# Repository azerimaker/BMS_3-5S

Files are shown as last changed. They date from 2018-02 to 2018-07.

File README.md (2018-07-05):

# BMS 3-5S
3-5S Battery Management System based on TI bq76920 IC and MSP430 uC. The design is largely influenced by the TI's [TIDA-00449](http://www.ti.com/tool/TIDA-00449) reference and LibreSolar's excellent [BMS-5s](https://github.com/LibreSolar/BMS-5s) designs.

## Specs:
- 3-5 Li-ion/Po Cells
- MSP430 Microcontroller for gas gauging, balancing and serial communication
- Load current: 50A (cont.), 100A (peak) (estimated!)
- You can find the PCB on Seeedstudio's [Fusion Gallery](https://www.seeedstudio.com/BMS-3-5S-g-1092928)

## Programming
- I'm using MSP430 Launchpad both to program the BMS in external target mode and to provide serial communication to PC. 

## Demo
- After modifying the TIDA-00449 firmware, which was designed for bq76930 (10S version) balancing and status report worked fine [(see here)](https://twitter.com/OrkhanAmirAslan/status/1014643359699406849)

## To Do in next Rev. 
- Add simple Python script to decode serial messages and print cell status
- Fix issues with battery voltage switching and Pre-Discharge mosfets. 
- Remove soldermask for high current tracks. 
- More pads for balancing resistors for higher power dissipation. 

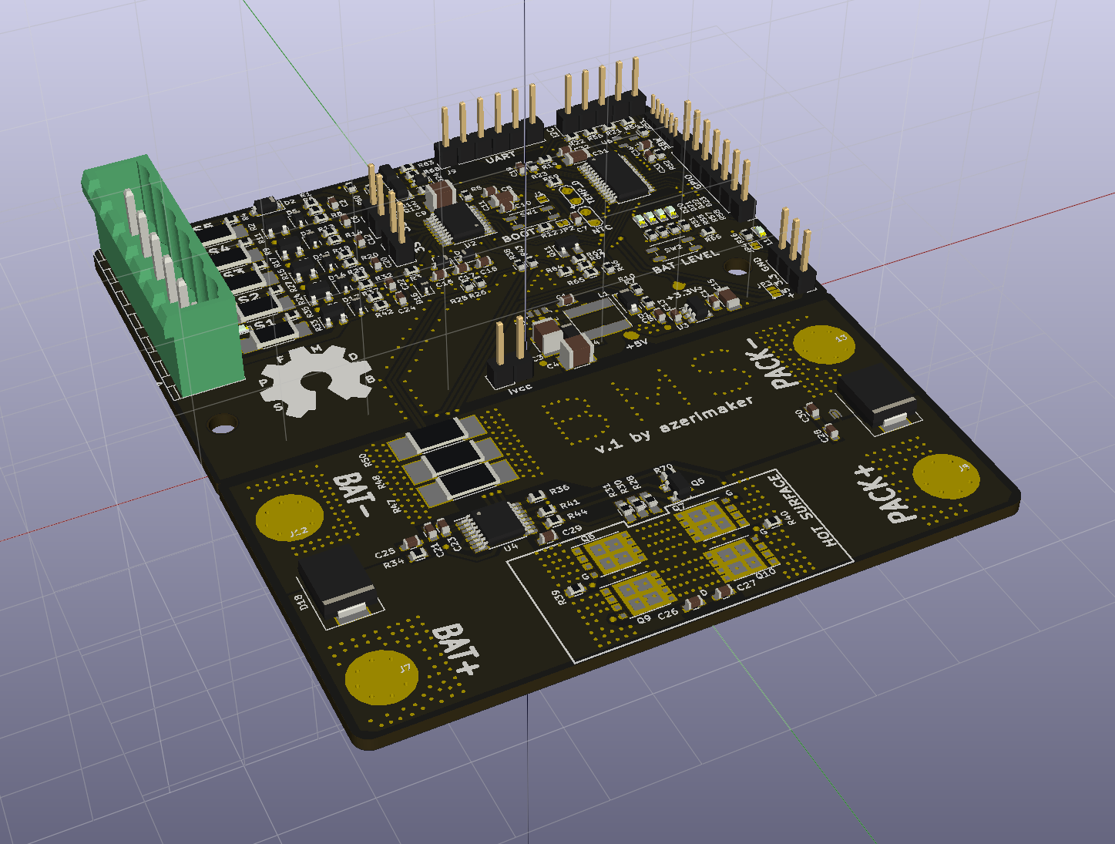
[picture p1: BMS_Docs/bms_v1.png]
BMS_v1 PCB Render


BMS_v1 PCB

<div align="center">
<br /> This work is licensed under a <a rel="license" href="http://creativecommons.org/licenses/by-sa/4.0/">Creative Commons Attribution-ShareAlike 4.0 International License</a>.

</div>

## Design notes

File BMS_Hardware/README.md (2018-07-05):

## BMS 3-5S Hardware Files

KiCAD version 4.0.7 was used.

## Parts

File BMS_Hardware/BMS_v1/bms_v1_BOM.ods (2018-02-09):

Reference | Quantity | Value | PART DESCRIPTION | Part Number | PCB Footprint | URL/Source
C10 C13 C8 | 3 | 1uF | min 10V |  | 0603 | --------------------
C11 C15 C31 | 3 | 4.7uF | CAP CER 4.7UF 50V X7R, min 10V | CL31B475KBHNNNE | 1206 | https://www.digikey.de/scripts/DkSearch/dksus.dll?Detail&itemSeq=247305398&uq=636514169459805309
C1 C12 C16 C17 C18 C2 C20 C22 C24 C32 C34 C6 | 12 | 100nF | - |  | 0603 | --------------------
C26 C27 C28 C30 | 4 | 100nF | CAP, CERM, 0.1uF, 100V, +/-10%, X7R, 0603 | GRM188R72A104KA35D | 0603 | https://www.digikey.de/scripts/DkSearch/dksus.dll?Detail&itemSeq=249808389&uq=636522696778252805
C14 C19 | 2 | 470pF | - |  | 0603 | --------------------
C21 | 1 | 220nF | - |  | 0603 | --------------------
C23 | 1 | 47nF | - |  | 0603 | --------------------
C25 C29 | 2 | 10nF | - |  | 0603 | --------------------
C33 | 1 | 2.2nF | - |  | 0603 | --------------------
C7 | 1 | 4.7nF | - |  | 0603 | --------------------
C3 C4 C5 C9 | 4 | 10uF | CAP CER 10UF 50V X7R | 1276-3387-1-ND | 1210 | https://www.digikey.de/scripts/DkSearch/dksus.dll?Detail&itemSeq=249808060&uq=636522694114372805
D11 | 1 | GREEN | Power Status LED |  | 0603 | --------------------
D6 D3 D8 D13 D15 | 1 | Cell 1-5 | Cell Status LEDs |  | 0603 | --------------------
D10 D16 D24 D9 | 4 | 3.3V | Zener Diode 3.3V 300mW | MM3Z3V3ST1G | SOD-323 | https://www.digikey.de/scripts/DkSearch/dksus.dll?Detail&itemSeq=247304155&uq=636494198338316196
D12 D14 D17 D5 D7 | 5 | 5.6V | Diode, Zener, 5.6V, 200mW | MMSZ5232BS-7-F | SOD-323 | https://www.digikey.de/scripts/DkSearch/dksus.dll?Detail&itemSeq=247269284&uq=636493840967967147
D18 D19 | 2 | SMCJ26A | TVS DIODE 26VWM 42.1V | SMCJ26A-E3/57T | DO-214AB | https://www.digikey.de/product-detail/en/vishay-semiconductor-diodes-division/SMCJ26A-E3-57T/SMCJ26A-E3-57TGICT-ND/2413420
D1 D2 | 2 | 1N4148W | DIODE GEN PURP 100V 300MA | 1N4148W-7-F | SOD-123 | https://www.digikey.de/scripts/DkSearch/dksus.dll?Detail&itemSeq=247300965&uq=636494163483703951
D20 D21 D22 D23 | 4 | Blue | Cell Voltage LEDs |  | 0603 | --------------------
D4 | 4 | DB2W40300L | DIODE SCHOTTKY 40V 3A MINI2 | DB2W40300L | SOD-123F | https://www.digikey.de/product-detail/en/panasonic-electronic-components/DB2W40300L/DB2W40300LCT-ND/3884376
E1 | 1 | SPARK_GAP |  |  | PCB footprint | --------------------
J1 | 1 | BOOT ON/OFF |  |  | Pin Header
J12 | 1 | BATT- |  |  | PCB footprint | --------------------
J13 | 1 | PACK- |  |  | PCB footprint | --------------------
J14 | 1 | I2C_CONN |  |  | Pin Header | --------------------
J15 | 1 | GPIO
J2 | 1 | Vcc_current |  |  | Pin Header | --------------------
J3 | 1 | Thermistor |  |  | Pin Header
J4 | 1 | 3-4S |  |  | Pin Header | --------------------
J5 | 1 | 3S |  |  | Pin Header | --------------------
J6 | 1 | VCC
J7 | 1 | BATT+ |  |  | PCB footprint | --------------------
J8 | 1 | PACK+ |  |  | PCB footprint | --------------------
J9 | 1 | UART |  |  | Pin Header | --------------------
J10 | 1 | SBW |  |  | Pin Header | --------------------
J11 | 1 | Balance Terminal |  |  | Pin Header | --------------------
JP1 JP2 JP4 | 1 | NC |  |  | PCB footprint | --------------------
JP3 | 1 | VCC_SELECT |  |  | PCB footprint | --------------------
L1 | 1 | 22uH | FIXED IND 22UH 1.4A 135 MOHM SMD | NRS6028T220MMGJV | 6.00mm x 6.00mm | https://www.digikey.de/scripts/DkSearch/dksus.dll?Detail&itemSeq=247306594&uq=636494220819346923
Q11 | 1 | RQ5A030AP | MOSFET P-CH 12V 3A TSMT3 | RQ5A030APTL | SC-96 | https://www.digikey.de/product-detail/en/texas-instruments/CSD23381F4/296-40002-1-ND/5177879
Q5 | 1 | ZXMP10A13F | MOSFET P-CH 100V 0.6A | ZXMP10A13FTA | SOT-23-3 | https://www.digikey.de/scripts/DkSearch/dksus.dll?Detail&itemSeq=247257927&uq=636494181879678553
Q10 Q6 Q7 Q9 | 4 | CSD18511Q5AT | N-Channel 40V 159A | CSD18511Q5AT | 8-VSONP | https://www.digikey.de/scripts/DkSearch/dksus.dll?Detail&itemSeq=247302673&uq=636494181879758569
Q1 Q2 Q3 Q4 Q8 | 3 | DMN2004K | MOSFET N-CH 20V 0.63A | DMN2004K-7 | SOT-23-3 | https://www.digikey.de/scripts/DkSearch/dksus.dll?Detail&itemSeq=247269061&uq=636493853394696489
Q12 | 1 | TP0610K-T1-GE3 | HV PFET |  | SOT-23-3 | https://www.digikey.de/scripts/DkSearch/dksus.dll?Detail&itemSeq=248928896&uq=636514210194332359
Q13 | 1 | BSS138 | Gen purpose n-fet |  | SOT-23-3
R10 R12 R13 R18 R29 R37 R52 R59 R6 R67 R68 | 11 | 10K |  |  | 0603 | --------------------
R21 R22 R3 | 3 | 4.7K |  |  | 0603 | --------------------
R23 | 1 | 500K |  |  | 0603 | --------------------
R28 R30 R31 | 3 | 330R |  |  | 0603 | --------------------
R15 R2 R24 R33 R9 | 5 | 33R | RES SMD 33 OHM 1% 1W 2010 | RMCP2010FT33R0 | 2010 | https://www.digikey.de/product-detail/en/stackpole-electronics-inc/RMCP2010FT33R0/RMCP2010FT33R0CT-ND/2505002
R36 R41 | 2 | 4R7 |  |  | 0603 | --------------------
R39 R40 | 2 | 1M |  |  | 0603 | --------------------
R45 R53 | 2 | 0 |  |  | 0603 | --------------------
R49 | 1 | Net-Tie |  |  | 0603 | --------------------
R47 R48 R50 | 3 | 2m | RES 0.002 OHM 1% 3W - 3x 0.006 Ohm | P17094CT-ND | 2512 | https://www.digikey.de/scripts/DkSearch/dksus.dll?Detail&itemSeq=247307811&uq=636494232585020202
R1 R11 R14 R16 R17 R19 R20 R27 R32 R35 R38 R4 R42 R43 R46 R51 R55 R57 R58 R64 R65 R8 | 22 | 1K |  |  | 0603 | --------------------
R25 R26 R34 R44 R5 R54 R56 | 7 | 100R |  |  | 0603 | --------------------
R62 | 1 | 154K | RES SMD 154K OHM 1% 1/10W | CRCW0603154KFKEA | 0603 | https://www.digikey.de/scripts/DkSearch/dksus.dll?Detail&itemSeq=247309315&uq=636494247609240202
R60 R61 R63 R69 | 4 | 100K
R66 | 1 | 4K7 |  |  | 0603 | --------------------
R7 | 1 | 52.3K |  |  | 0603
SW1 | 1 | BOOT | Push button |  | Buttons_Switches_SMD:SW_SPST_EVQP2
SW2 | 1 | LED_Read | Push button |  | Buttons_Switches_SMD:SW_SPST_EVQP2
TP1, TP2 | 2 | 5V, 3.3V |  |  | PCB footprint | --------------------
U1 | 1 | MCP16301 | IC REG BUCK ADJ 0.6A | MCP16301T-I/CHY | SOT23-6 | https://www.digikey.de/scripts/DkSearch/dksus.dll?Detail&itemSeq=247271130&uq=636493853394726492
U2 | 1 | BQ7692003PWR | Battery Monitor IC | BQ7692003PWR | 20-TSSOP | https://www.digikey.de/product-detail/en/texas-instruments/BQ7692003PWR/296-39959-1-ND/5177836
U3 | 1 | TLV70233DBV | IC REG LINEAR 3.3V 300MA | TLV70233DBVR | SOT23-5 | https://www.digikey.de/product-detail/en/texas-instruments/TLV70233DBVR/296-32415-1-ND/3505572
U4 | 1 | BQ76200 | HIGH-SIDE N-CH FET DRVR | BQ76200PWR | 16-TSSOP | https://www.digikey.de/scripts/DkSearch/dksus.dll?Detail&itemSeq=247307289&uq=636494227248039728
U5 | 1 | LMT01LPG | 0.5°C Accurate 2-Pin Digital NTC | LMT01LPGM | TO-92-2 | https://www.digikey.de/scripts/DkSearch/dksus.dll?Detail&itemSeq=247307372&uq=636494228223361588
U6 | 1 | TPS3839G33 | IC LP SUPERVISRY CIRCUIT Vth 3.08V | TPS3839G33DBZR | SOT-23-3 | https://www.digikey.de/product-detail/en/texas-instruments/TPS3839G33DBZR/296-35470-1-ND/3748993
U7 | 1 | MSP430G2553IPW28 | IC MCU 16BIT 16KB FLASH | MSP430G2553IPW28 | 28-TSSOP | https://www.digikey.de/scripts/DkSearch/dksus.dll?Detail&itemSeq=248928807&uq=636514210194332359

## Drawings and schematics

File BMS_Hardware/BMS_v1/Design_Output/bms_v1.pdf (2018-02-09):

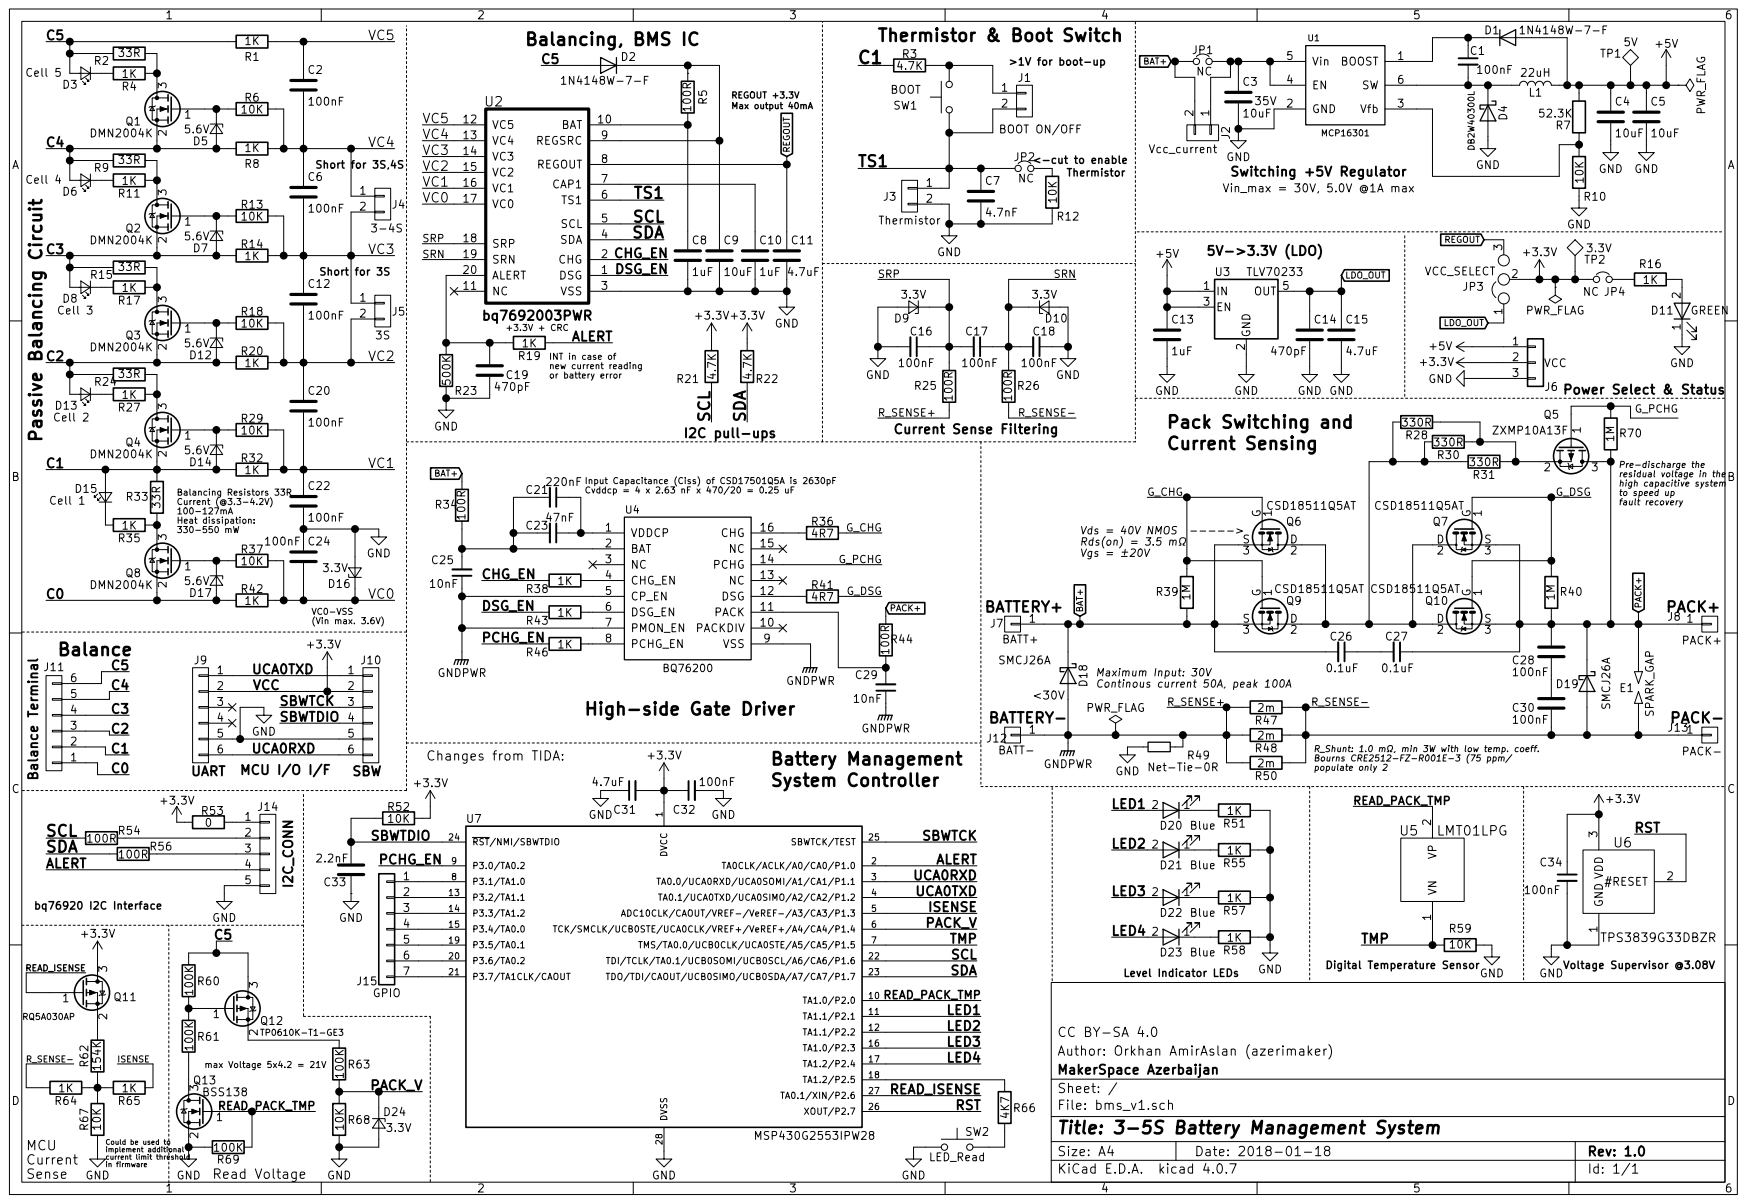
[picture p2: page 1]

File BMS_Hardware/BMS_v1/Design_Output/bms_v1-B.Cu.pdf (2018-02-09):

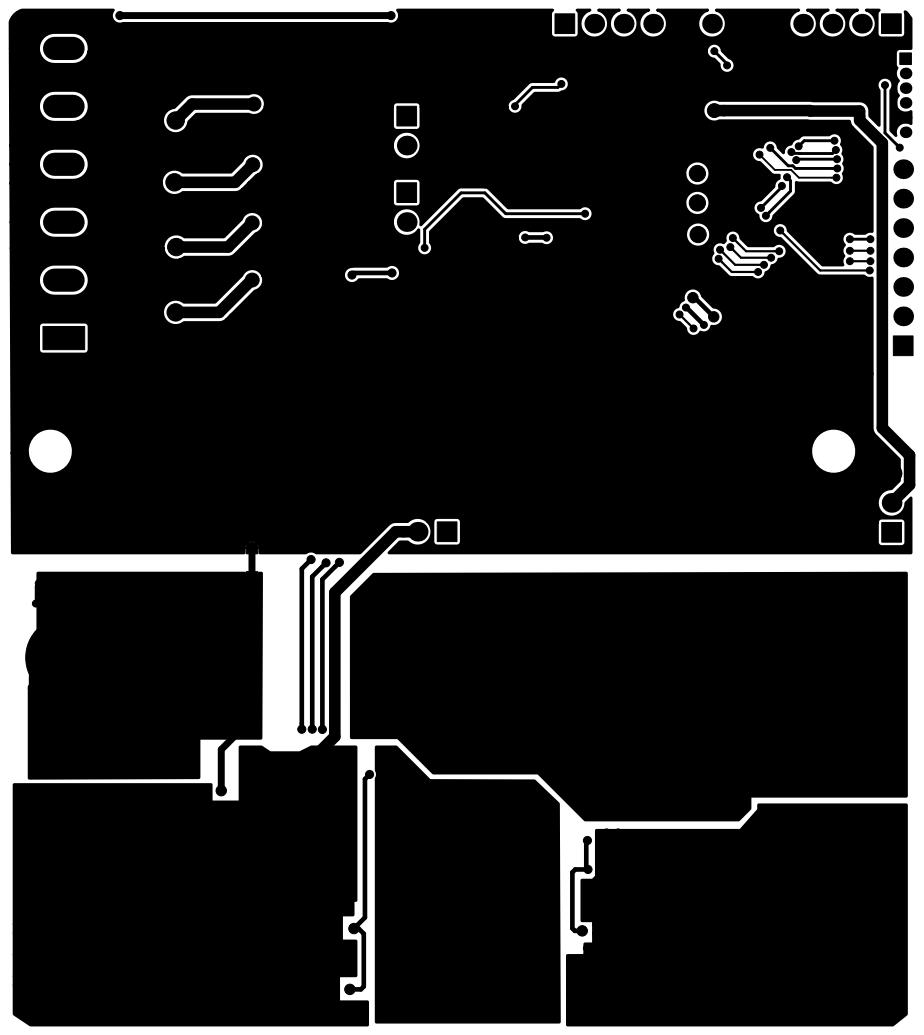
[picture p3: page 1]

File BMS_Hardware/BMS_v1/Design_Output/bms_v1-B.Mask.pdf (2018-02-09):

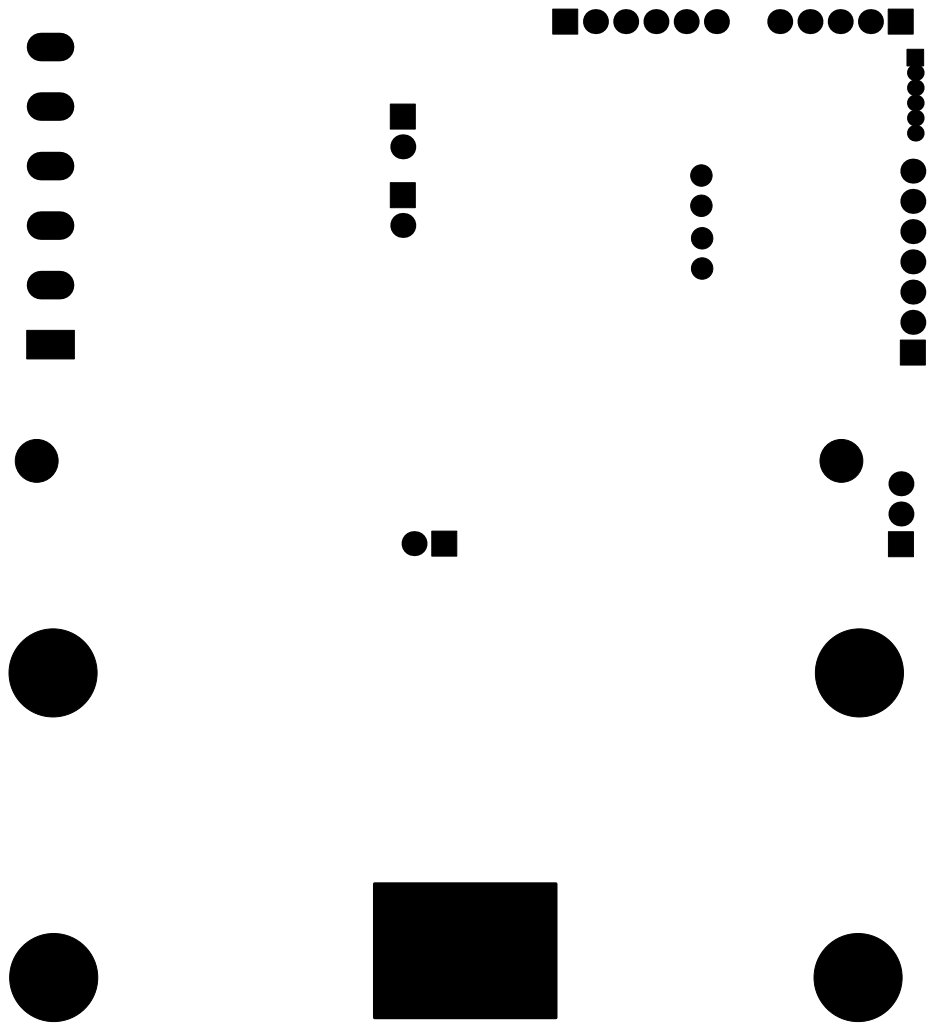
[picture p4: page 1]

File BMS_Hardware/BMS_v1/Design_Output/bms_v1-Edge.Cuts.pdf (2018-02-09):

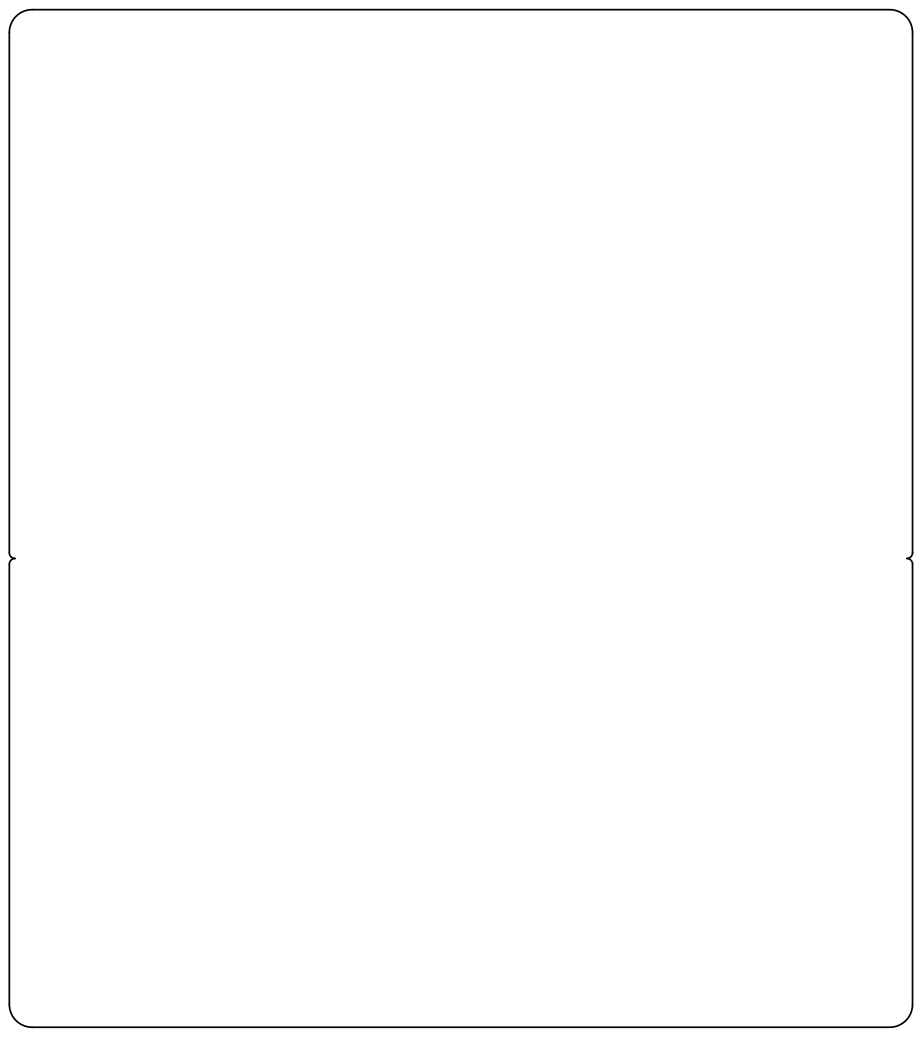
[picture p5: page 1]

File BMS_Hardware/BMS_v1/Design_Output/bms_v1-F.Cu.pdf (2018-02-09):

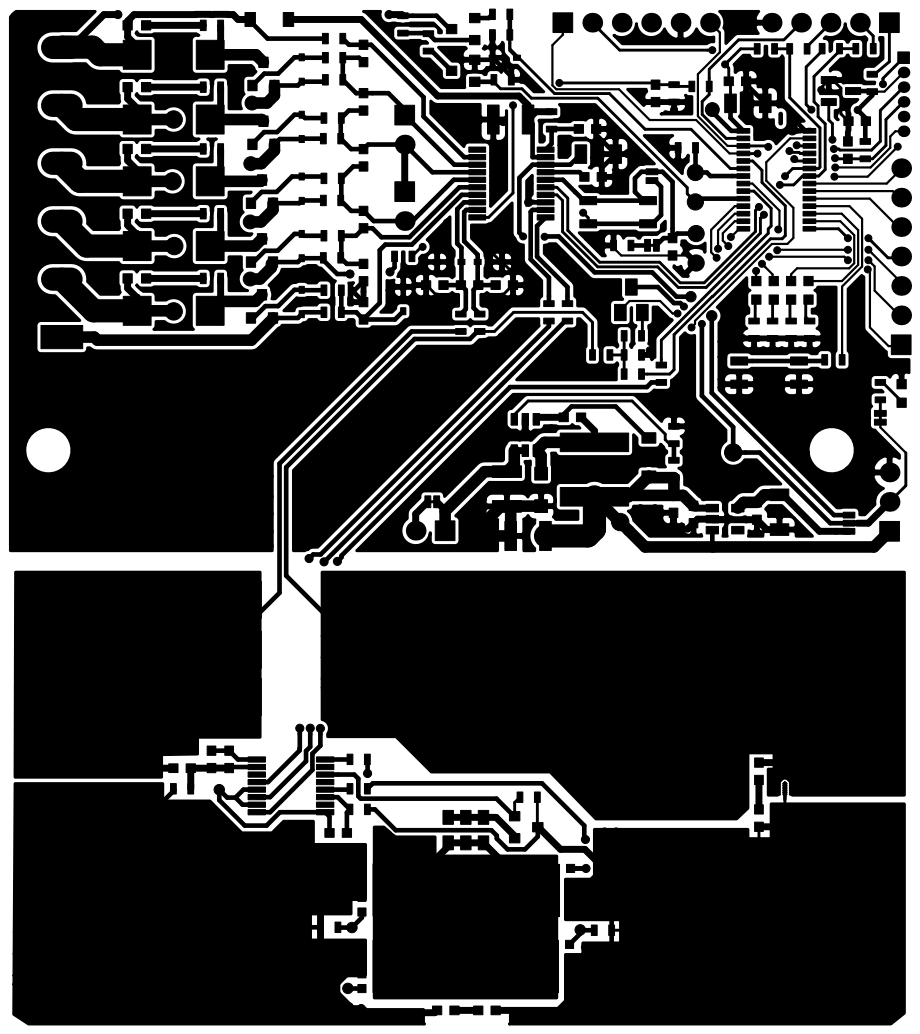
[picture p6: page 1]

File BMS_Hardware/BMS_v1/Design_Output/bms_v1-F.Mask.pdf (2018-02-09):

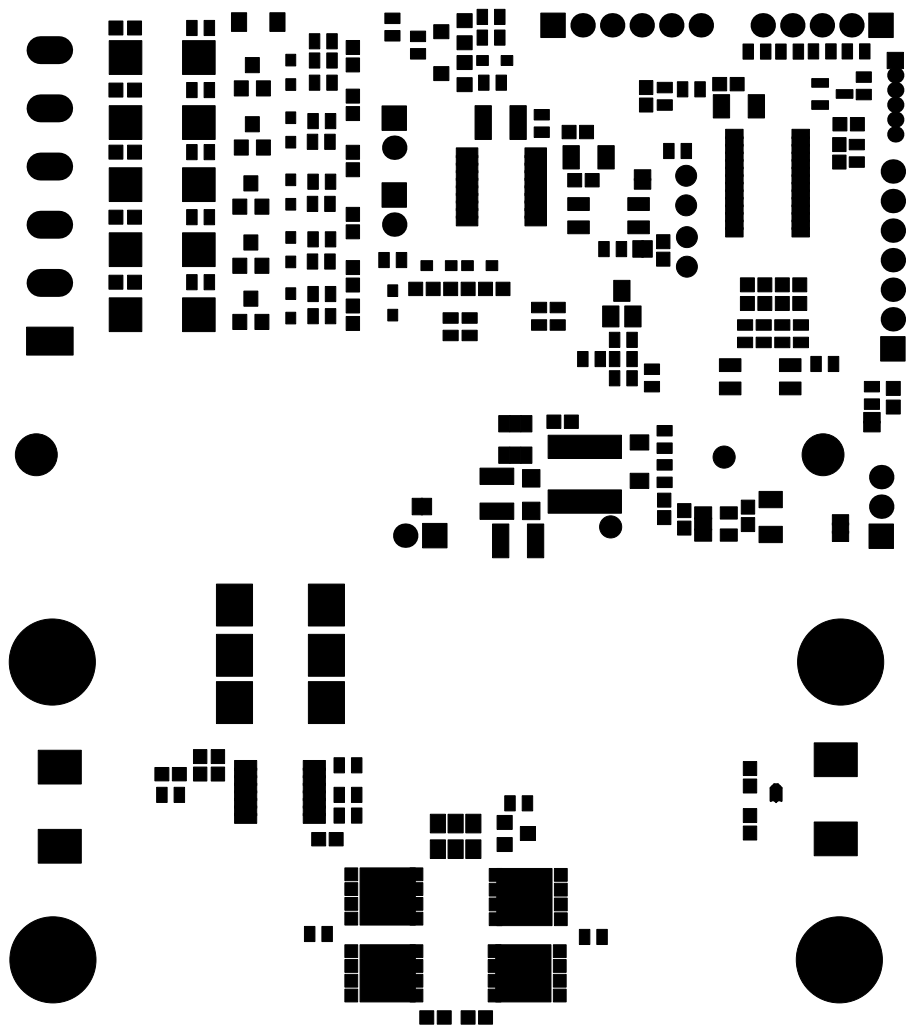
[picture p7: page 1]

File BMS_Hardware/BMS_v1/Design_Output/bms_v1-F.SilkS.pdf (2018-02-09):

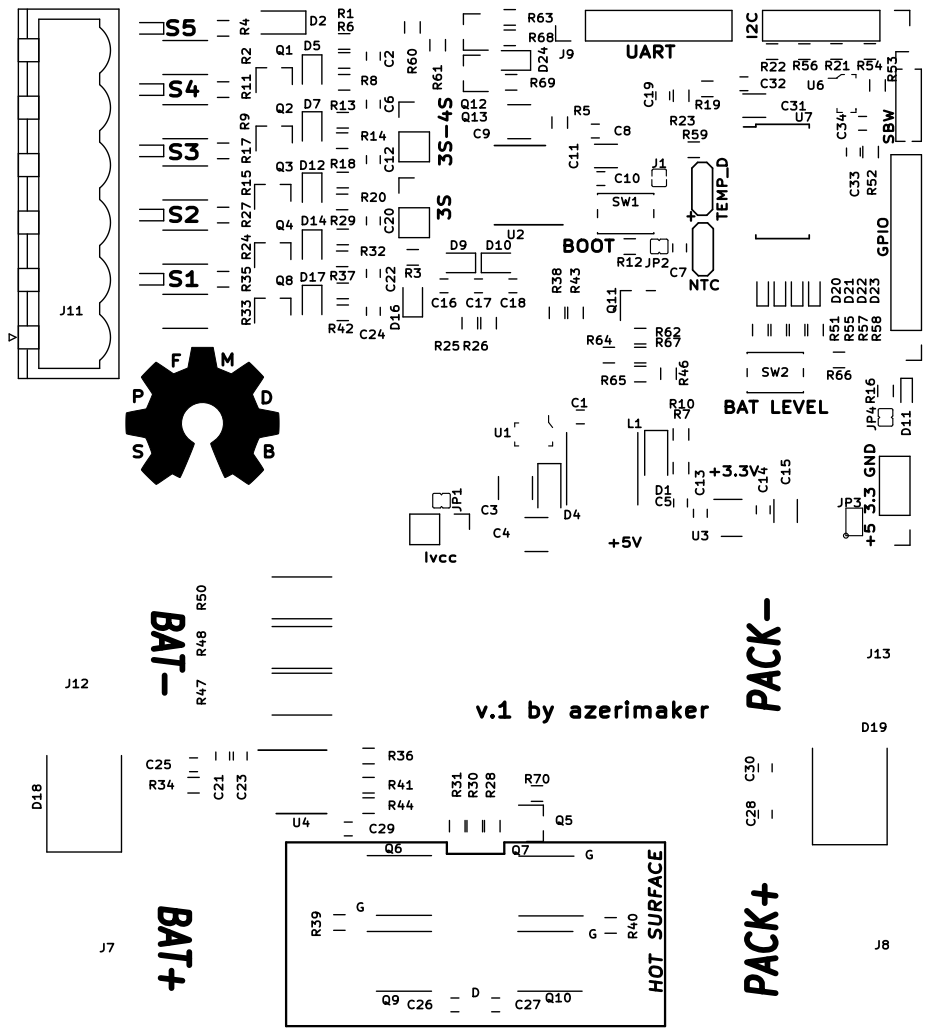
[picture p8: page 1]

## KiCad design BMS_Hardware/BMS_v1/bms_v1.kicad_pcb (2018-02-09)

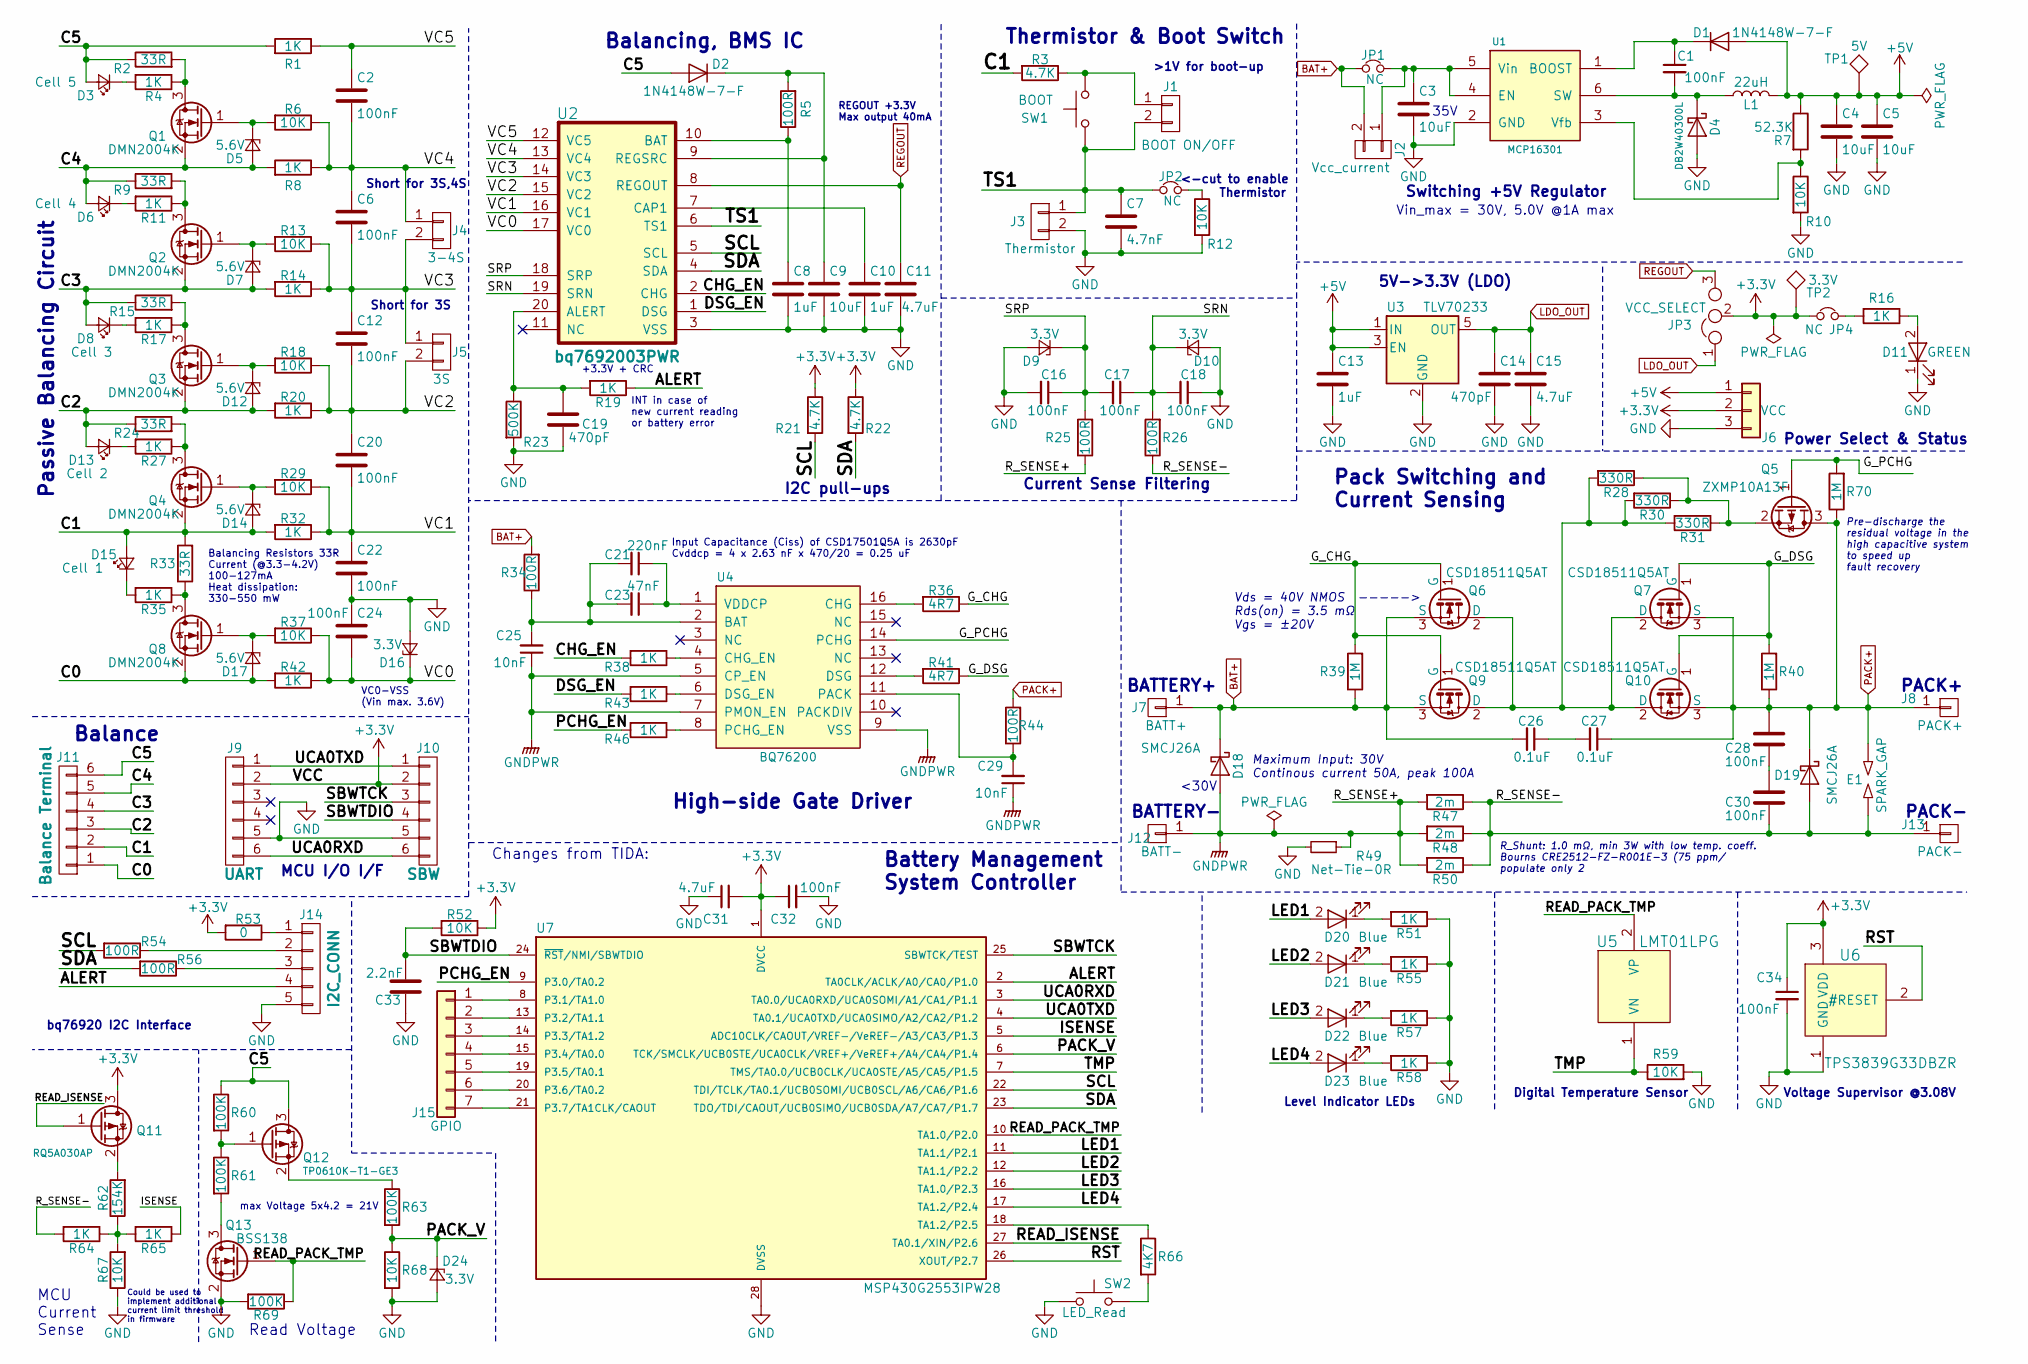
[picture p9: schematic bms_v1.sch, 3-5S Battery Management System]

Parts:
C1, C2, C6, C12, C16, C17, C18, C20, C22, C24, C28, C30, C32, C34: 100nF; C_0603
C3, C4, C9: 10uF; C_1210
C5: 10uF; C_0603
C7: 4.7nF; C_0603
C8, C10, C13: 1uF; C_0603
C11, C15, C31: 4.7uF; C_1206
C14, C19: 470pF; C_0603
C21: 220nF; C_0603
C23: 47nF; C_0603
C25, C29: 10nF; C_0603
C26, C27: 0.1uF; C_0603
C33: 2.2nF; C_0603
D1, D2: 1N4148W-7-F; D_SOD-123
D3: Cell 5; LED_0603
D4: DB2W40300L; D_SOD-123F
D5, D7, D12, D14, D17: 5.6V; D_SOD-323
D6: Cell 4; LED_0603
D8: Cell 3; LED_0603
D9, D10, D16, D24: 3.3V; D_SOD-323
D11: GREEN; LED_0603
D13: Cell 2; LED_0603
D15: Cell 1; LED_0603
D18, D19: SMCJ26A; D_SMC
D20, D21, D22, D23: Blue; LED_0603
E1: SPARK_GAP; Spark_Gap_1.65x1.1
J1: BOOT ON/OFF; jumper_NO
J2: Vcc_current; Pin_Header_Straight_1x02_Pitch2.54mm
J3: Thermistor; Test_Point_2Pads
J4: 3-4S; Pin_Header_Straight_1x02_Pitch2.54mm
J5: 3S; Pin_Header_Straight_1x02_Pitch2.54mm
J6: VCC; Pin_Header_Straight_1x03_Pitch2.54mm
J7: BATT+; MountingHole_3.5mm_Pad_Via
J8: PACK+; MountingHole_3.5mm_Pad_Via
J9: UART; Pin_Header_Straight_1x06_Pitch2.54mm
J10: SBW; Pin_Header_Straight_1x06_Pitch1.27mm
J11: Balance Terminal; PhoenixContact_MSTBVA-G_06x5.00mm_Vertical
J12: BATT-; MountingHole_3.5mm_Pad_Via
J13: PACK-; MountingHole_3.5mm_Pad_Via
J14: I2C_CONN; Pin_Header_Straight_1x05_Pitch2.54mm
J15: GPIO; Pin_Header_Straight_1x07_Pitch2.54mm
JP1, JP2, JP4: NC; jumper_NC
JP3: VCC_SELECT; JP_NO_NC
L1: 22uH; L_Taiyo-Yuden_NR-60xx
Q1, Q2, Q3, Q4, Q8: DMN2004K; SOT-23
Q5: ZXMP10A13F; SOT-23
Q6, Q7, Q9, Q10: CSD18511Q5AT; VSONP-8-1EP_5x6_Pitch1.27mm(GDS)
Q11: RQ5A030AP; SuperSOT-3
Q12: TP0610K-T1-GE3; SOT-23
Q13: BSS138; SOT-23
R1, R4, R8, R11, R14, R16, R17, R19, R20, R27, R32, R35, R38, R42, R43, R46, R51, R55, R57, R58, R64, R65: 1K; R_0603
R2, R9, R15, R24, R33: 33R; R_2010_HandSoldering
R3, R21, R22: 4.7K; R_0603
R5, R25, R26, R34, R44, R54, R56: 100R; R_0603
R6, R10, R12, R13, R18, R29, R37, R52, R59, R67, R68: 10K; R_0603
R7: 52.3K; R_0603
R23: 500K; R_0603
R28, R30, R31: 330R; R_0603_HandSoldering
R36, R41: 4R7; R_0603
R39, R40, R70: 1M; R_0603
R47, R48, R50: 2m; R_2512_HandSoldering
R49: Net-Tie-0R; R_0603_HandSoldering
R53: 0; R_0603
R60, R61, R63, R69: 100K; R_0603
R62: 154K; R_0603
R66: 4K7; R_0603
SW1: BOOT; SW_SPST_EVQP2
SW2: LED_Read; SW_SPST_EVQP2
TP1: 5V; Measurement_Point_Round-SMD-Pad_Small
TP2: 3.3V; Measurement_Point_Round-SMD-Pad_Small
U1: MCP16301; SOT-23-6
U2: bq7692003PWR; TSSOP-20_4.4x6.5mm_Pitch0.65mm
U3: TLV70233; SOT-23-5
U4: BQ76200; TSSOP-16_4.4x5mm_Pitch0.65mm
U5: LMT01LPG; Test_Point_2Pads
U6: TPS3839G33DBZR; SOT-23-3
U7: MSP430G2553IPW28; TSSOP-28_4.4x9.7mm_Pitch0.65mm

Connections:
+3V3: C31.2, C32.1, C34.1, J6.2, J9.2, J10.2, JP3.2, JP4.1, Q11.3 (D), R21.1, R22.1, R52.1, R53.2, TP2.1, U6.3 (VDD), U7.1 (DVCC)
+5V: C4.1, C5.1, C13.1, D1.2 (A), J6.1, L1.2, R7.1, TP1.1, U3.1 (IN), U3.3 (EN)
/ALERT: J14.4, R19.1, U7.2 (TA0CLK/ACLK/A0/CA0/P1.0)
/C0: D17.2 (A), J11.1, Q8.2 (S), R42.2
/C1: D14.2 (A), D15.2 (A), J11.2, Q4.2 (S), R3.2, R32.2, R33.2
/C2: D12.2 (A), D13.2 (A), J11.3, Q3.2 (S), R20.2, R24.1
/C3: D7.2 (A), D8.2 (A), J11.4, Q2.2 (S), R14.2, R15.1
/C4: D5.2 (A), D6.2 (A), J11.5, Q1.2 (S), R8.2, R9.1
/C5: D2.2 (A), D3.2 (A), J11.6, Q12.3 (D), R1.2, R2.1, R60.1
/CHG_EN: R38.2, U2.2 (CHG)
/DSG_EN: R43.2, U2.1 (DSG)
/G_CHG: Q6.1 (G), Q9.1 (G), R36.1, R39.2
/G_DSG: Q7.1 (G), Q10.1 (G), R40.2, R41.1
/ISENSE: R65.1, U7.5 (ADC10CLK/CAOUT/VREF-/VeREF-/A3/CA3/P1.3)
/LED1: D20.2 (A), U7.11 (TA1.1/P2.1)
/LED2: D21.2 (A), U7.12 (TA1.1/P2.2)
/LED3: D22.2 (A), U7.16 (TA1.0/P2.3)
/LED4: D23.2 (A), U7.17 (TA1.2/P2.4)
/PACK_V: D24.1 (K), R63.2, R68.1, U7.6 (TCK/SMCLK/UCB0STE/UCA0CLK/VREF+/VeREF+/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)
/PCHG_EN: R46.2, U7.9 (P3.0/TA0.2)
/READ_ISENSE: Q11.1 (G), U7.27 (TA0.1/XIN/P2.6)
/READ_PACK_TMP: Q13.1 (G), R69.1, U5.2 (VP), U7.10 (TA1.0/P2.0)
/RST: U6.2 (#RESET), U7.26 (XOUT/P2.7)
/R_SENSE-: C30.2, D19.2 (A), E1.2, J13.1, R26.1, R47.1, R48.1, R50.1, R64.2
/SBWTCK: J10.3, U7.25 (SBWTCK/TEST)
/SBWTDIO: C33.1, J10.4, R52.2, U7.24 (~RST~/NMI/SBWTDIO)
/SCL: R21.2, R54.2, U2.5 (SCL), U7.22 (TDI/TCLK/TA0.1/UCB0SOMI/UCB0SCL/A6/CA6/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)
/SDA: R22.2, R56.2, U2.4 (SDA), U7.23 (TDO/TDI/CAOUT/UCB0SIMO/UCB0SDA/A7/CA7/P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)
/SRN: C17.1, C18.2, D10.1 (K), R26.2, U2.19 (SRN)
/SRP: C16.1, C17.2, D9.1 (K), R25.2, U2.18 (SRP)
/TMP: R59.1, U5.1 (VN), U7.7 (TMS/TA0.0/UCB0CLK/UCA0STE/A5/CA5/P1.5)
/TS1: C7.1, J1.2, J3.1, JP2.1, SW1.2, U2.6 (TS1)
/UCA0RXD: J9.6, J10.6, U7.3 (TA0.0/UCA0RXD/UCA0SOMI/A1/CA1/P1.1)
/UCA0TXD: J9.1, J10.1, U7.4 (TA0.1/UCA0TXD/UCA0SIMO/A2/CA2/P1.2)
/VC0: C24.2, D16.1 (K), R37.1, R42.1, U2.17 (VC0)
/VC1: C20.2, C22.1, R29.1, R32.1, U2.16 (VC1)
/VC2: C12.2, C20.1, J5.2, R18.1, R20.1, U2.15 (VC2)
/VC3: C6.2, C12.1, J4.2, J5.1, R13.1, R14.1, U2.14 (VC3)
/VC4: C2.2, C6.1, J4.1, R6.1, R8.1, U2.13 (VC4)
/VC5: C2.1, R1.1, U2.12 (VC5)
BAT+: C26.2, D18.1 (K), J2.2, J7.1, JP1.1, Q6.3 (S), Q9.3 (S), R34.2, R39.1
GND: C3.2, C4.2, C5.2, C7.2, C8.2, C9.2, C10.2, C11.2, C13.2, C14.2, C15.2, C16.2, C18.1, C19.2, C22.2, C24.1, C31.1, C32.2, C33.2, C34.2, D4.2 (A), D9.2 (A), D10.2 (A), D11.1 (K), D16.2 (A), D24.2 (A), J3.2, J6.3, J9.5, J10.5, J14.5, Q13.2 (S), R10.2, R12.2, R23.2, R49.2, R51.1, R55.1, R57.1, R58.1, R59.2, R67.1, R68.2, R69.2, SW2.1, U1.2 (GND), U2.3 (VSS), U3.2 (GND), U6.1 (GND), U7.28 (DVSS)
GNDPWR: C25.1, C29.1, D18.2 (A), J12.1, R25.1, R47.2, R48.2, R49.1, R50.2, U4.5 (CP_EN), U4.7 (PMON_EN), U4.9 (VSS)
LDO_OUT: C14.1, C15.1, JP3.1, U3.5 (OUT)
unnamed: C1.1, D1.1 (K), U1.1 (BOOST)
unnamed: C1.2, D4.1 (K), L1.1, U1.6 (SW)
unnamed: C3.1, J2.1, JP1.2, U1.4 (EN), U1.5 (Vin)
unnamed: C8.1, R5.1, U2.10 (BAT)
unnamed: C9.1, D2.1 (K), R5.2, U2.9 (REGSRC)
unnamed: C10.1, U2.7 (CAP1)
unnamed: C19.1, R19.2, R23.1, U2.20 (ALERT)
unnamed: C21.1, C23.1, U4.1 (VDDCP)
unnamed: C21.2, C23.2, C25.2, R34.1, U4.2 (BAT)
unnamed: C26.1, C27.2
unnamed: C28.2, C30.1
unnamed: C29.2, R44.1, U4.11 (PACK)
unnamed: D3.1 (K), R4.2
unnamed: D5.1 (K), Q1.1 (G), R6.2
unnamed: D6.1 (K), R11.2
unnamed: D7.1 (K), Q2.1 (G), R13.2
unnamed: D8.1 (K), R17.2
unnamed: D11.2 (A), R16.1
unnamed: D12.1 (K), Q3.1 (G), R18.2
unnamed: D13.1 (K), R27.2
unnamed: D14.1 (K), Q4.1 (G), R29.2
unnamed: D15.1 (K), R35.2
unnamed: D17.1 (K), Q8.1 (G), R37.2
unnamed: D20.1 (K), R51.2
unnamed: D21.1 (K), R55.2
unnamed: D22.1 (K), R57.2
unnamed: D23.1 (K), R58.2
unnamed: J1.1, R3.1, SW1.1
unnamed: J14.1, R53.1
unnamed: J14.2, R54.1
unnamed: J14.3, R56.1
unnamed: J15.1, U7.8 (P3.1/TA1.0)
unnamed: J15.2, U7.13 (P3.2/TA1.1)
unnamed: J15.3, U7.14 (P3.3/TA1.2)
unnamed: J15.4, U7.15 (P3.4/TA0.0)
unnamed: J15.5, U7.19 (P3.5/TA0.1)
unnamed: J15.6, U7.20 (P3.6/TA0.2)
unnamed: J15.7, U7.21 (P3.7/TA1CLK/CAOUT)
unnamed: JP2.2, R12.1
unnamed: JP4.2, R16.2
unnamed: Q1.3 (D), R2.2, R4.1
unnamed: Q2.3 (D), R9.2, R11.1
unnamed: Q3.3 (D), R15.2, R17.1
unnamed: Q4.3 (D), R24.2, R27.1
unnamed: Q5.1 (G), R70.2
unnamed: Q5.2 (S), R28.1, R30.1, R31.1
unnamed: Q8.3 (D), R33.1, R35.1
unnamed: Q6.2 (D), Q7.2 (D), Q9.2 (D), Q10.2 (D), R28.2, R30.2, R31.2
unnamed: Q11.2 (S), R62.2
unnamed: Q12.1 (G), R60.2, R61.1
unnamed: Q12.2 (S), R63.1
unnamed: Q13.3 (D), R61.2
unnamed: R7.2, R10.1, U1.3 (Vfb)
unnamed: R36.2, U4.16 (CHG)
unnamed: R38.1, U4.4 (CHG_EN)
unnamed: R41.2, U4.12 (DSG)
unnamed: R43.1, U4.6 (DSG_EN)
unnamed: R46.1, U4.8 (PCHG_EN)
unnamed: R62.1, R64.1, R65.2, R67.2
unnamed: R66.1, U7.18 (TA1.2/P2.5)
unnamed: R66.2, SW2.2
PACK+: C27.1, C28.1, D19.1 (K), E1.1, J8.1, Q5.3 (D), Q7.3 (S), Q10.3 (S), R40.1, R44.2, R70.1
REGOUT: C11.1, JP3.3, U2.8 (REGOUT)

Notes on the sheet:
Balancing, BMS IC
Battery Management System Controller
MCU I/O I/F
<-cut to enable Thermistor
BATTERY-
BATTERY+
PACK-
PACK+
REGOUT +3.3V Max output 40mA
Thermistor & Boot Switch
bq76920 I2C Interface
Power Select & Status
R_Shunt: 1.0 mΩ, min 3W with low temp. coeff. Bourns CRE2512-FZ-R001E-3 (75 ppm/ populate only 2
MCU Current Sense
Read Voltage
Digital Temperature Sensor
Voltage Supervisor @3.08V
Short for 3S
Short for 3S,4S
Balancing Resistors 33R Current (@3.3-4.2V) 100-127mA Heat dissipation: 330-550 mW
Passive Balancing Circuit
VC0-VSS (Vin max. 3.6V)
INT in case of new current reading or battery error
+3.3V + CRC
>1V for boot-up
I2C pull-ups
35V
Switching +5V Regulator
Vin_max = 30V, 5.0V @1A max
5V->3.3V (LDO)
<30V
Current Sense Filtering
Maximum Input: 30V Continous current 50A, peak 100A
Changes from TIDA:
Pre-discharge the residual voltage in the high capacitive system to speed up fault recovery
Pack Switching and Current Sensing
Balance
Input Capacitance (Ciss) of CSD17501Q5A is 2630pF Cvddcp = 4 x 2.63 nF x 470/20 = 0.25 uF
High-side Gate Driver
Vds = 40V NMOS -----> Rds(on) = 3.5 mΩ Vgs = ±20V

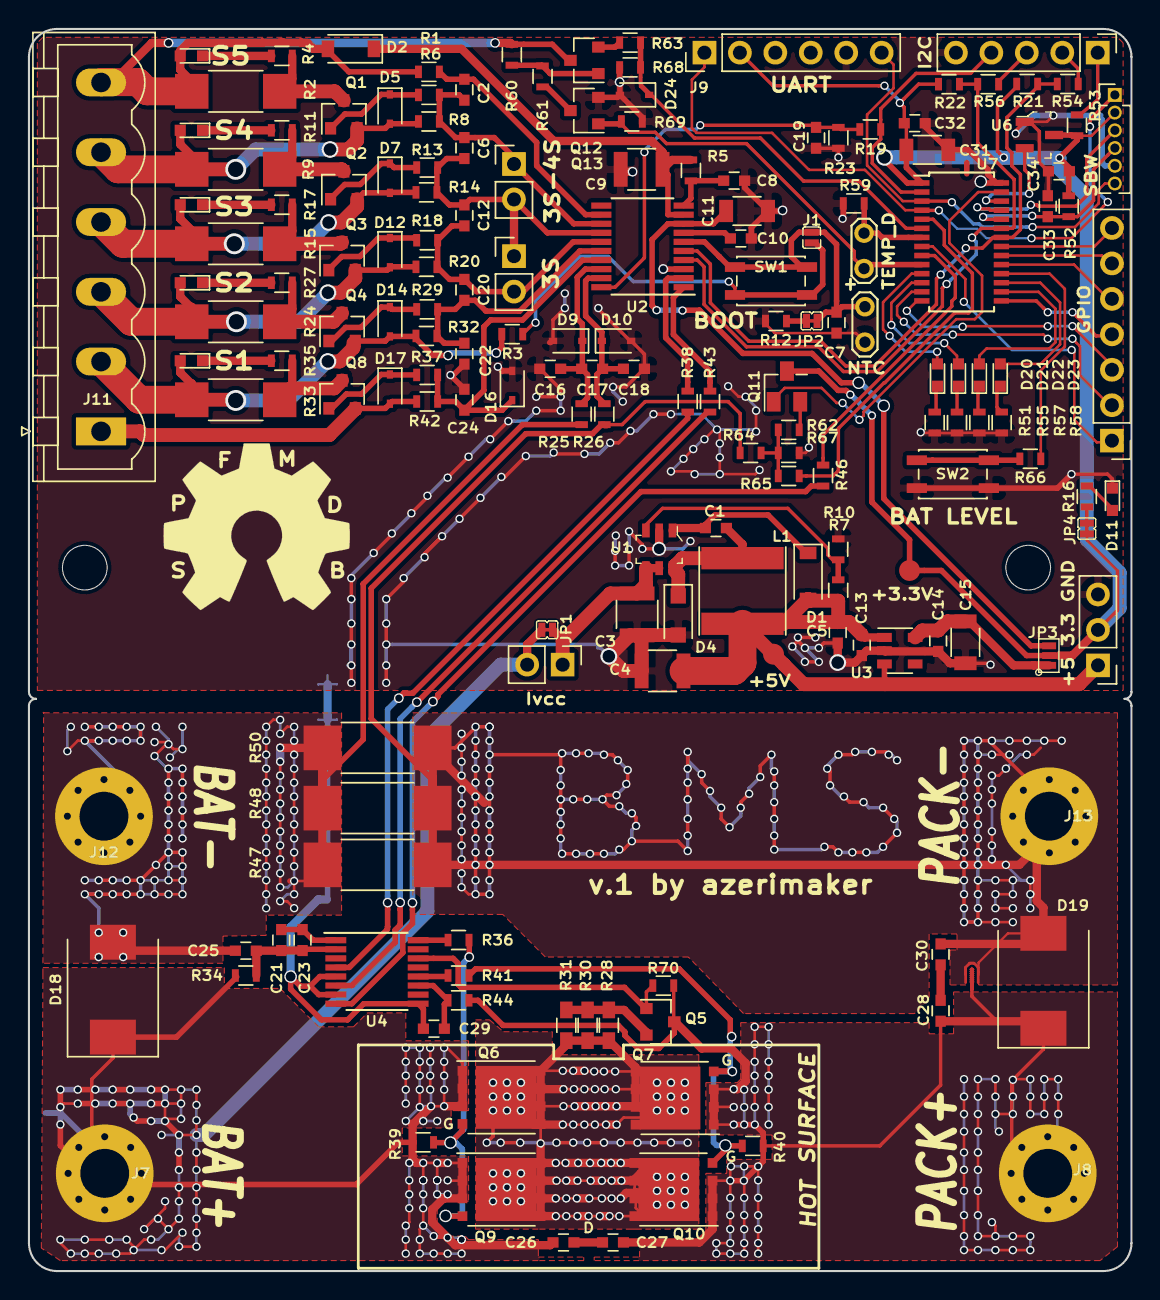
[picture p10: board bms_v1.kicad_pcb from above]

Board: 2 copper layers, 79.0 x 89.0 mm, 172 parts (1 on the bottom side), 107 nets.

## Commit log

2018-02-09 BMS_v1 HW files
    BMS_v1 is my first attempt to produce 3-5S BMS board. Board is largely modified around the reference design TIDA-00449 from TI.
    [bms_v1-B.Cu.gbl, bms_v1-B.Mask.gbs, bms_v1-B.SilkS.gbo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]
2018-02-09 Adding BMSv1 render
2018-02-09 BMS 3D render added
2018-02-15 addings PCB pic
2018-03-17 initial version of the firmware
    This is the initial version of the bms_v1 firmware, it's not not finished. Use at your own risk.
2018-07-05 pcb link added
2018-07-05 kicad note
